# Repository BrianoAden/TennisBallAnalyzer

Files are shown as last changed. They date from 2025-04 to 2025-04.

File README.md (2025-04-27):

# Introduction
Hi! My name is Aden Briano, and I've created this repository to store all of the code developed for a Tennis Ball Analyzer project I'm working on.
# General Overview
The goal of this project is to create a handheld device capable of testing the suitability of tennis balls for competitive play. 
# Code Overview
Insert Text Here

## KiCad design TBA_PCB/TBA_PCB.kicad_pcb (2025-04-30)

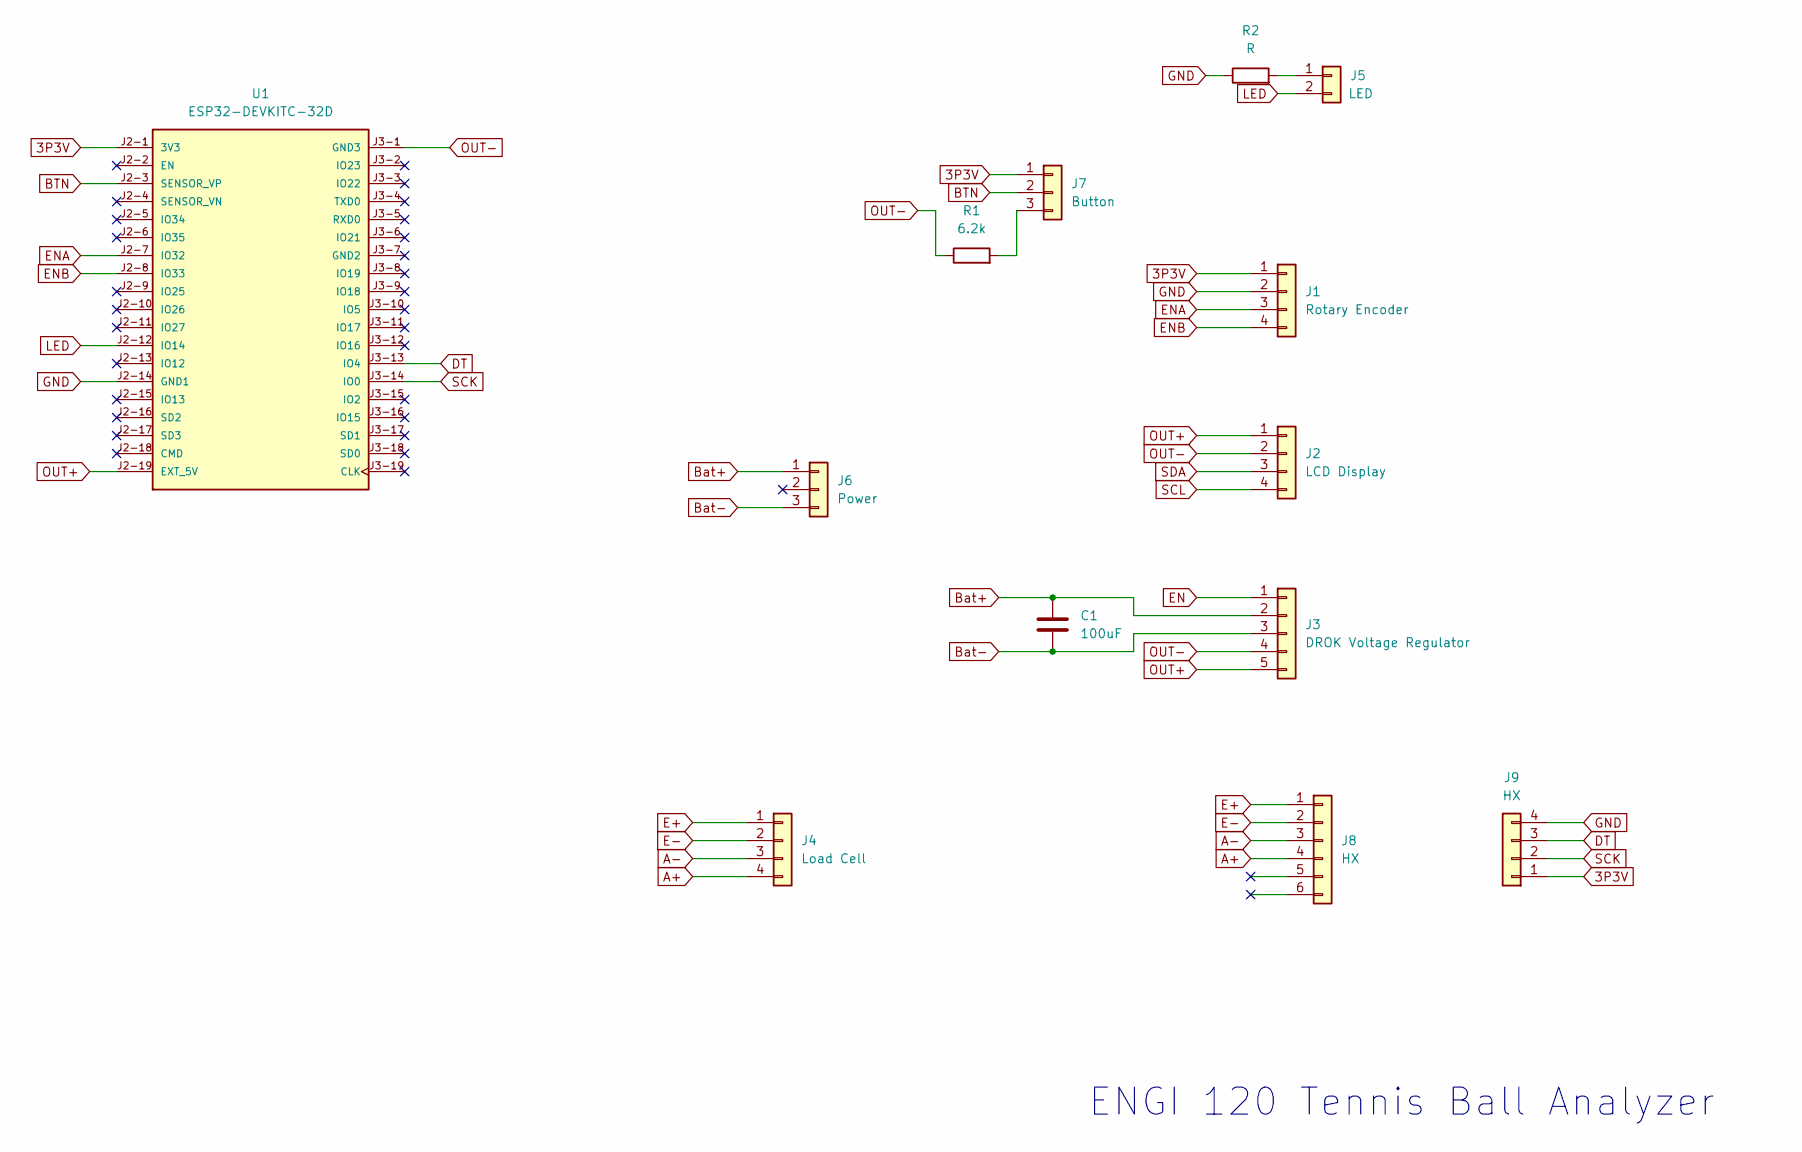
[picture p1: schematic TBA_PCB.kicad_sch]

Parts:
C1: 100uF; CP_Radial_D4.0mm_P2.00mm
J1: Rotary Encoder; PinHeader_1x04_P2.54mm_Vertical
J2: LCD Display; PinHeader_1x04_P2.54mm_Vertical
J3: DROK Voltage Regulator; PinHeader_1x05_P2.54mm_Vertical
J4: Load Cell; PinHeader_1x04_P2.54mm_Vertical
J5: LED; PinHeader_1x02_P2.54mm_Vertical
J6: Power; PinHeader_1x03_P2.54mm_Vertical
J7: Button; PinHeader_1x03_P2.54mm_Vertical
J8: HX; PinHeader_1x06_P2.54mm_Vertical
J9: HX; PinHeader_1x04_P2.54mm_Vertical
R1: 6.2k; R_Axial_DIN0204_L3.6mm_D1.6mm_P2.54mm_Vertical
R2: R; R_Axial_DIN0204_L3.6mm_D1.6mm_P2.54mm_Vertical
U1: ESP32-DEVKITC-32D; MODULE_ESP32-DEVKITC-32D; PARTREV V4

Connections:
3P3V: J1.1, J7.1, J9.1, U1.J2-1 (3V3)
A+: J4.4, J8.4
A-: J4.3, J8.3
BTN: J7.2, U1.J2-3 (SENSOR_VP)
Bat+: C1.1, J3.2, J6.1
Bat-: C1.2, J3.3, J6.3
DT: J9.3, U1.J3-13 (IO4)
E+: J4.1, J8.1
E-: J4.2, J8.2
EN: J3.1
ENA: J1.3, U1.J2-7 (IO32)
ENB: J1.4, U1.J2-8 (IO33)
GND: J1.2, J9.4, R2.1, U1.J2-14 (GND1)
LED: J5.2, U1.J2-12 (IO14)
unnamed: J5.1, R2.2
unnamed: J7.3, R1.2
OUT+: J2.1, J3.5, U1.J2-19 (EXT_5V)
OUT-: J2.2, J3.4, R1.1, U1.J3-1 (GND3)
SCK: J9.2, U1.J3-14 (IO0)
SCL: J2.4
SDA: J2.3

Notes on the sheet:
ENGI 120 Tennis Ball Analyzer

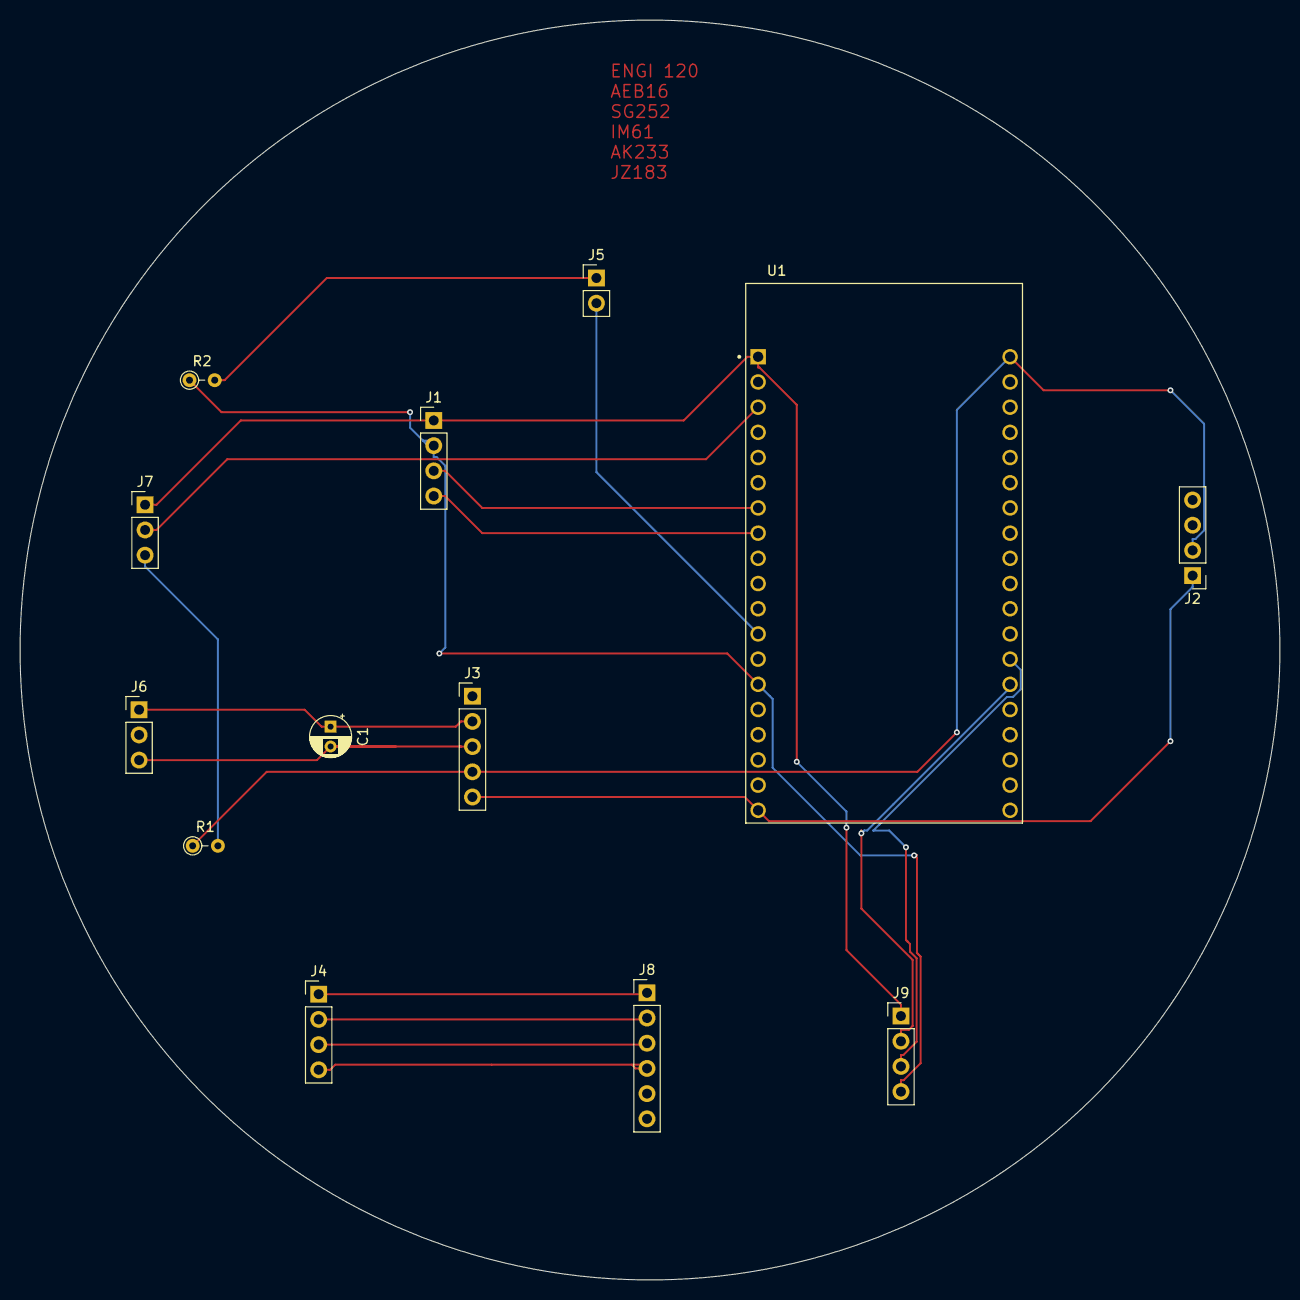
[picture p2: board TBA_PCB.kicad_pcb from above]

Board: 2 copper layers, 127.0 x 127.0 mm, 13 parts (0 on the bottom side), 18 nets.

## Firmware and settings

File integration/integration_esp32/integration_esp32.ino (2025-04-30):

/*
* The purpose of this file is to integrate the rotary encoder and load cell, so that they may be used simultaneously.
*/

#include "HX711_ADC.h"
#include "LiquidCrystal_I2C.h"
#include "math.h"

//https://github.com/olkal/HX711_ADC documentation for library!
//credits to DIYEngineers for helping with calibration https://www.diyengineers.com/2022/05/19/load-cell-with-hx711-how-to-use-with-examples/
//credits to https://electricdiylab.com/how-to-connect-optical-rotary-encoder-with-arduino/ for rotary encoder help

int stiff_co = 0;
int flag = 0;
float forward_deformation = 0;

//timing
unsigned long t = 0;

const int ENCODER_A = 32;
const int ENCODER_B = 33;

// HX711 circuit wiring + macros
const int LOADCELL_DOUT_PIN = 4;
const int LOADCELL_SCK_PIN = 0;
float data = 0;

//calibrate load cell (value obtained from load_cell_calibration.ino)
const float calibrationValue = 201.64;
float displacement = 0;


//Rotary Encoder constants
volatile long temp, encoder_value = 0;  //This variable will increase or decrease depending on the rotation of encoder
//float PINION_DIAMETER = 19.5;        //mm
//float PINION_CIRCUMFERENCE = 61.26;  //mm
float PINION_DIAMETER = 27.3;         //mm
float PINION_CIRCUMFERENCE = 85;  //mm

const int buttonPin = 36;  //pin to read state of Button
int buttonState = 0;


HX711_ADC LoadCell(LOADCELL_DOUT_PIN, LOADCELL_SCK_PIN);
//LiquidCrystal lcd(12, 11, 7, 6, 5, 4); //previous 16x2 LCD display
LiquidCrystal_I2C lcd(0x27, 20, 4);

void setup() {
  //start the lcd
  lcd.init();
  lcd.backlight();

  //set baudrate
  Serial.begin(115200);
  lcd.clear();
  lcd.print("Booting...");

  //initilaize load cell
  LoadCell.begin();

  loadCellCalibration();  //calibrate the loadcell

  lcd.clear();
  lcd.print("Booting complete");

  pinMode(ENCODER_A, INPUT_PULLUP);  // internal pullup input pin 2

  pinMode(ENCODER_B, INPUT_PULLUP);  // internal pullup input pin 3

  pinMode(14, OUTPUT);

  pinMode(buttonPin, INPUT);  //initialize buttonPin to read inputs

  //Setting up interrupt
  attachInterrupt(digitalPinToInterrupt(ENCODER_A), encoder_isr, CHANGE);
}

void loop() {
  static boolean newDataReady = 0;
  const int serialPrintInterval = 0;  //increase value to slow down serial print activity

  // check for new data/start next conversion:
  if (LoadCell.update()) newDataReady = true;

  // get smoothed value from the dataset:
  if (newDataReady) {
    if (millis() > t + serialPrintInterval) {

      data = LoadCell.getData();
      int force = (data / 1000) * 9.81;  //converting grams into force newtons

      if (flag == 0){
        //LCD Print
        lcd.clear();          // Clears the display
        lcd.setCursor(0, 0);  // set the cursor to column 0, line 0
        lcd.print("Force(N):" + String(int(force)));
        lcd.setCursor(0, 1);  // set the cursor to column 0, line 1
        displacement = -((encoder_value / 1200.0) * PINION_CIRCUMFERENCE);
        lcd.print("Position:" + String(displacement));  //print out distance traveled in mm
        Serial.println("Position: " + String(displacement)); 
        if (force == 80) {
          forward_deformation = displacement;
          digitalWrite(14, HIGH);
          // Serial.print(",");
          // Serial.print(displacement);
          flag = 1;
        }
      }else{
        delay(1000);
        lcd.clear();
        stiff_co = (80)/(displacement/10);
        if ((stiff_co > 108) && (stiff_co < 148)){
          lcd.print("Competitive");
          //Serial.println("Competitive");
        }else if ((stiff_co <= 108) && (stiff_co > 86)){
          lcd.print("Practice!");
          // Serial.println("Not Competitive");
        }else{
          lcd.print("Recycle!");
        }
        lcd.setCursor(0,1);
        lcd.print("FD: " + String(forward_deformation) + "mm");
        //Serial.println(stiff_co);
      }

      //Print to Serial Monitor
      // Serial.print("Mass(g):");
      // Serial.println(data);

      // // //testing yields S1200p P/R for our rotary encoder
      if (encoder_value != temp)
        Serial.println(encoder_value);


      newDataReady = 0;
      t = millis();
    }
  }
  buttonState = digitalRead(buttonPin);
  if (buttonState == HIGH) {
    Serial.print("Reset!");
    rotaryEncoderReset();
    loadCellCalibration();
    digitalWrite(14, LOW);
    flag = 0;
  }
}

/*
* Helper function to reset and calibrate load cell. Probably not as necessary as rotary encoder reset since the 
* Load cell zeroes itself out anyway.
*/

void loadCellCalibration() {

  //zero out load cell. VERY important.
  unsigned long stabilizingtime = 2000;
  LoadCell.start(stabilizingtime, true);

  LoadCell.setCalFactor(calibrationValue);
}

/*
* Helper function to reset the rotary encoder. This will likely only occur at a user's button press. The purpose is to
* help with measurements of multiple balls without having to manually restart Arduino. 
*/

void rotaryEncoderReset() {

  encoder_value = 0;
  temp = 0;
}

void encoder_isr() {

  // If the state of A changed, it means the encoder has been rotated
  if ((digitalRead(ENCODER_A) == HIGH) != (digitalRead(ENCODER_B) == LOW)) {
    encoder_value--;
  } else {
    encoder_value++;
  }
}

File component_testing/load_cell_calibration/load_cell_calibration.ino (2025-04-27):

#include <HX711_ADC.h>
#if defined(ESP8266)|| defined(ESP32) || defined(AVR)
#include <EEPROM.h>
#endif

//pins:
const int HX711_dout = 14; //mcu > HX711 dout pin
const int HX711_sck = 15; //mcu > HX711 sck pin

//HX711 constructor:
HX711_ADC LoadCell(HX711_dout, HX711_sck);

const int calVal_eepromAdress = 0;
unsigned long t = 0;

void setup() {
  Serial.begin(57600); delay(10);
  Serial.println();
  Serial.println("Starting...");

  LoadCell.begin();
  //LoadCell.setReverseOutput(); //uncomment to turn a negative output value to positive
  unsigned long stabilizingtime = 2000; // preciscion right after power-up can be improved by adding a few seconds of stabilizing time
  boolean _tare = true; //set this to false if you don't want tare to be performed in the next step
  LoadCell.start(stabilizingtime, _tare);
  if (LoadCell.getTareTimeoutFlag() || LoadCell.getSignalTimeoutFlag()) {
    Serial.println("Timeout, check MCU>HX711 wiring and pin designations");
    while (1);
  }
  else {
    LoadCell.setCalFactor(1.0); // user set calibration value (float), initial value 1.0 may be used for this sketch
    Serial.println("Startup is complete");
  }
  while (!LoadCell.update());
  calibrate(); //start calibration procedure
}

void loop() {
  static boolean newDataReady = 0;
  const int serialPrintInterval = 0; //increase value to slow down serial print activity

  // check for new data/start next conversion:
  if (LoadCell.update()) newDataReady = true;

  // get smoothed value from the dataset:
  if (newDataReady) {
    if (millis() > t + serialPrintInterval) {
      float i = LoadCell.getData();
      Serial.print("Load_cell output val: ");
      Serial.println(i);
      newDataReady = 0;
      t = millis();
    }
  }

  // receive command from serial terminal
  if (Serial.available() > 0) {
    char inByte = Serial.read();
    if (inByte == 't') LoadCell.tareNoDelay(); //tare
    else if (inByte == 'r') calibrate(); //calibrate
    else if (inByte == 'c') changeSavedCalFactor(); //edit calibration value manually
  }

  // check if last tare operation is complete
  if (LoadCell.getTareStatus() == true) {
    Serial.println("Tare complete");
  }

}

void calibrate() {
  Serial.println("***");
  Serial.println("Start calibration:");
  Serial.println("Place the load cell an a level stable surface.");
  Serial.println("Remove any load applied to the load cell.");
  Serial.println("Send 't' from serial monitor to set the tare offset.");

  boolean _resume = false;
  while (_resume == false) {
    LoadCell.update();
    if (Serial.available() > 0) {
      if (Serial.available() > 0) {
        char inByte = Serial.read();
        if (inByte == 't') LoadCell.tareNoDelay();
      }
    }
    if (LoadCell.getTareStatus() == true) {
      Serial.println("Tare complete");
      _resume = true;
    }
  }

  Serial.println("Now, place your known mass on the loadcell.");
  Serial.println("Then send the weight of this mass (i.e. 100.0) from serial monitor.");

  float known_mass = 0;
  _resume = false;
  while (_resume == false) {
    LoadCell.update();
    if (Serial.available() > 0) {
      known_mass = Serial.parseFloat();
      if (known_mass != 0) {
        Serial.print("Known mass is: ");
        Serial.println(known_mass);
        _resume = true;
      }
    }
  }

  LoadCell.refreshDataSet(); //refresh the dataset to be sure that the known mass is measured correct
  float newCalibrationValue = LoadCell.getNewCalibration(known_mass); //get the new calibration value

  Serial.print("New calibration value has been set to: ");
  Serial.print(newCalibrationValue);
  Serial.println(", use this as calibration value (calFactor) in your project sketch.");
  Serial.print("Save this value to EEPROM adress ");
  Serial.print(calVal_eepromAdress);
  Serial.println("? y/n");

  _resume = false;
  while (_resume == false) {
    if (Serial.available() > 0) {
      char inByte = Serial.read();
      if (inByte == 'y') {
#if defined(ESP8266)|| defined(ESP32)
        EEPROM.begin(512);
#endif
        EEPROM.put(calVal_eepromAdress, newCalibrationValue);
#if defined(ESP8266)|| defined(ESP32)
        EEPROM.commit();
#endif
        EEPROM.get(calVal_eepromAdress, newCalibrationValue);
        Serial.print("Value ");
        Serial.print(newCalibrationValue);
        Serial.print(" saved to EEPROM address: ");
        Serial.println(calVal_eepromAdress);
        _resume = true;

      }
      else if (inByte == 'n') {
        Serial.println("Value not saved to EEPROM");
        _resume = true;
      }
    }
  }

  Serial.println("End calibration");
  Serial.println("***");
  Serial.println("To re-calibrate, send 'r' from serial monitor.");
  Serial.println("For manual edit of the calibration value, send 'c' from serial monitor.");
  Serial.println("***");
}

void changeSavedCalFactor() {
  float oldCalibrationValue = LoadCell.getCalFactor();
  boolean _resume = false;
  Serial.println("***");
  Serial.print("Current value is: ");
  Serial.println(oldCalibrationValue);
  Serial.println("Now, send the new value from serial monitor, i.e. 696.0");
  float newCalibrationValue;
  while (_resume == false) {
    if (Serial.available() > 0) {
      newCalibrationValue = Serial.parseFloat();
      if (newCalibrationValue != 0) {
        Serial.print("New calibration value is: ");
        Serial.println(newCalibrationValue);
        LoadCell.setCalFactor(newCalibrationValue);
        _resume = true;
      }
    }
  }
  _resume = false;
  Serial.print("Save this value to EEPROM adress ");
  Serial.print(calVal_eepromAdress);
  Serial.println("? y/n");
  while (_resume == false) {
    if (Serial.available() > 0) {
      char inByte = Serial.read();
      if (inByte == 'y') {
#if defined(ESP8266)|| defined(ESP32)
        EEPROM.begin(512);
#endif
        EEPROM.put(calVal_eepromAdress, newCalibrationValue);
#if defined(ESP8266)|| defined(ESP32)
        EEPROM.commit();
#endif
        EEPROM.get(calVal_eepromAdress, newCalibrationValue);
        Serial.print("Value ");
        Serial.print(newCalibrationValue);
        Serial.print(" saved to EEPROM address: ");
        Serial.println(calVal_eepromAdress);
        _resume = true;
      }
      else if (inByte == 'n') {
        Serial.println("Value not saved to EEPROM");
        _resume = true;
      }
    }
  }
  Serial.println("End change calibration value");
  Serial.println("***");
}

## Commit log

2025-04-04 fixed rotary encoder code
    [integration.ino, load_cell_calibration.ino, rotary_encoder_test.ino]
2025-04-06 made code more modular and included rotary encoder reset
    [integration.ino]
2025-04-14 separated functionalities into esp32 and arduino compatible
2025-04-27 including allcode and files worked on prior to Engineering showcase
    [TBA_PCB.kicad_pcb, TBA_PCB.kicad_sch]
2025-04-30 included practice threshold, updated PCB, gathered new data to plot
    [TBA_PCB-B_Cu.gbr, TBA_PCB-B_Mask.gbr, TBA_PCB-B_Paste.gbr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]
